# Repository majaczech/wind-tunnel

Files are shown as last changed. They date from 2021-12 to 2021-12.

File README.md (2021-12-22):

# 3D Printed Wind Tunnel
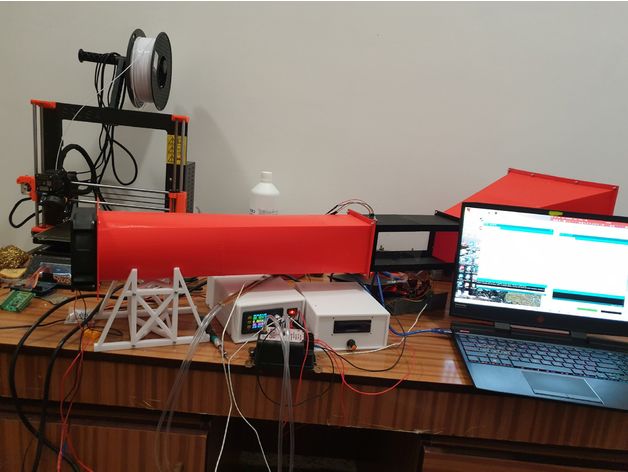
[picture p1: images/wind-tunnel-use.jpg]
3D Printed Wind Tunnel


This is 3D printed wind tunnel with Arduino-based unit. 

This source describes Open Hardware and is licensed under the CERN-OHL-S v2

**Experience with Arduino platform is required and supervision from a qualified electric engineering professional.**

**The project is prototype under development and authors are not responsible for any damages or injuries caused by inappropriate construction or operation.**
**This source is distributed WITHOUT ANY EXPRESS OR IMPLIED WARRANTY, INCLUDING OF MERCHANTABILITY, SATISFACTORY QUALITY AND FITNESS FOR A PARTICULAR PURPOSE.**

# References
1.	B.J. McCaffrey, G. Heskestad,A robust bidirectional low-velocity probe for flame and fire application, Combustion and Flame, Volume 26, 1976, Pages 125-127, ISSN 0010-2180, https://doi.org/10.1016/0010-2180(76)90062-6.
2.	Mauro, Stefano & Lanzafame, Rosario & Messina, Michele & Brusca, S. & Famoso, Fabio & Galvagno, Antonio. (2017). Small-Scale Open-Circuit Wind Tunnel: Design Criteria, Construction and Calibration. International Journal of Applied Engineering Research. 12. 13649-13662.
3.	The JeeLabs Shop. (n.d.). Retrieved February 11, 2021, from https://www.digitalsmarties.net/products/wind-sensor-rev-p
4.	Wind sensor REV. p - low Cost Anemometer. (n.d.). Retrieved February 12, 2021, from https://moderndevice.com/product/wind-sensor-rev-p/
5.	How can i tell if a case fan is sucking or blowing air? (2019, December 30). Retrieved February 13, 2021, from https://www.computerhope.com/issues/ch001151.htm
6.	Prohasky, Daniel & Watkins, Simon. (2014). Low cost hot-element anemometry versus the TFI Cobra.
7.	Thingiverse.com. (n.d.). The ultimate box maker BY HEARTMAN. Retrieved February 12, 2021, from https://www.thingiverse.com/thing:1264391
8.	T H Yong and S S Dol 2015 IOP Conf. Ser.: Mater. Sci. Eng. 78 012039

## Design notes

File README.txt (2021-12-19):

This thing was created by Majaczech, and is licensed under cc-sa.

Bench-Scale Wind-Tunnel for Callibration Pressure Probes accesible also from Thingiverse: https://www.thingiverse.com/thing:4601994

In order to safely built and operate the testing apparatus, experience with Arduino platform is required and supervision from a qualified electric engineering professional.

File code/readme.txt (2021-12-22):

This is improved demo sketch file from http://moderndevice.com/product/wind-sensor-rev-p/

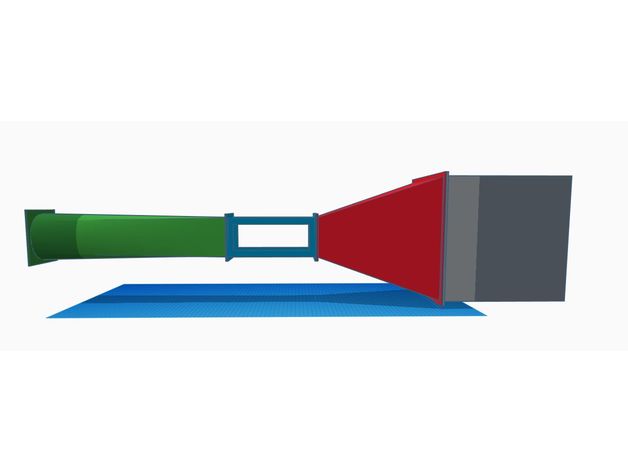
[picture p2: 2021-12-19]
images/Design.jpg

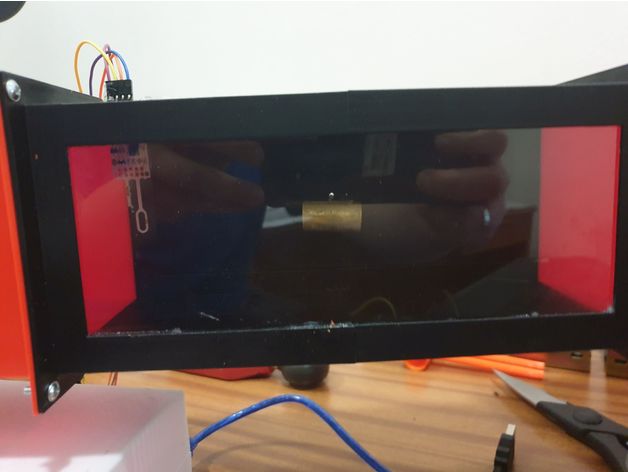
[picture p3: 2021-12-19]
images/BDVP-callibration.jpg

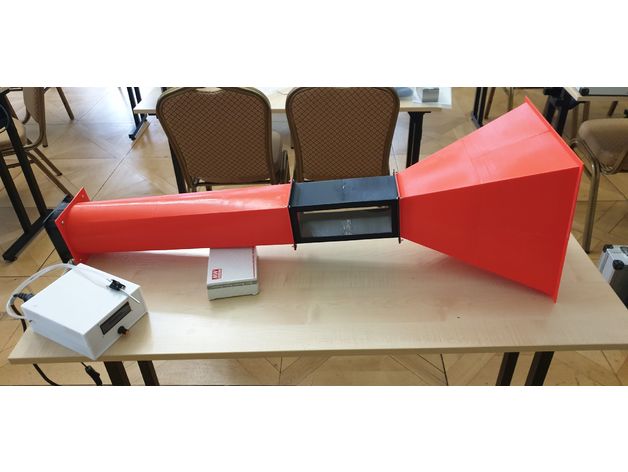
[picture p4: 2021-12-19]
images/Tunnel-2.jpg

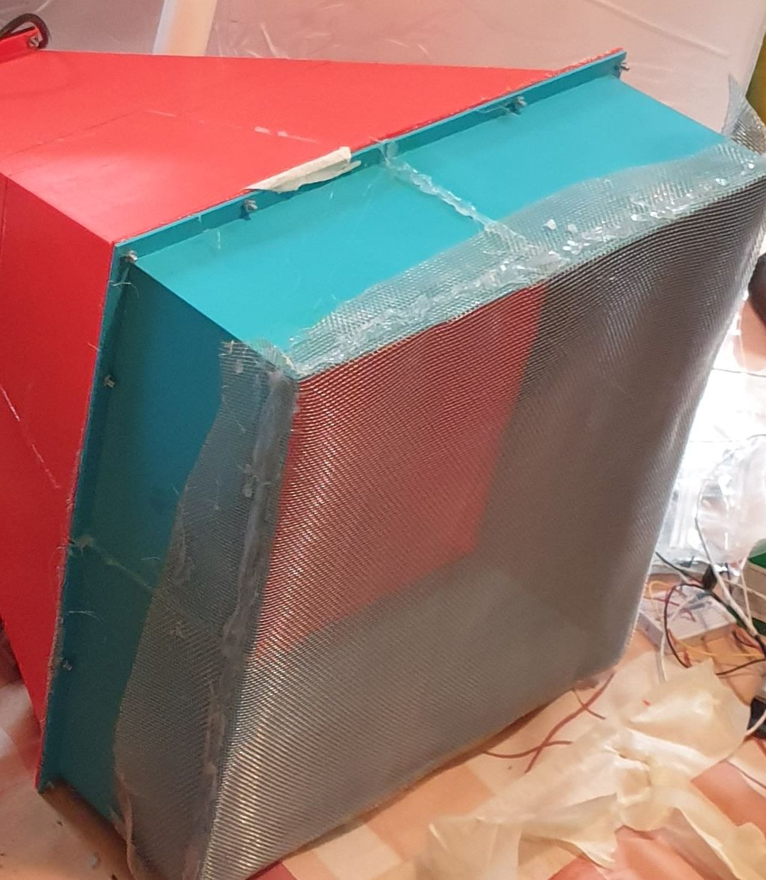
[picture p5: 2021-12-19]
images/settling-section.jpg

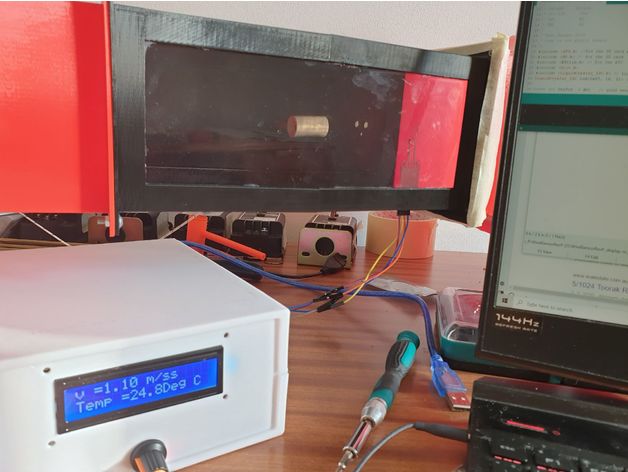
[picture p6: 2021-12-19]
images/in-sude.jpg

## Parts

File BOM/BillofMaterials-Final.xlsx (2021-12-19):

Designator | Component | Number | Cost per unit | Total cost [€] | Source of materials | Material type | WWW
 |  |  | [€]
Arduino UNO | Arduino Uno | 1 | 20 | 20 | Arduino | Electronics | https://store.arduino.cc/arduino-uno-rev3
LCD Display | Standard LCD 16x2 + extras - white on blue | 1 | 8.21 | 8.21 | Adafruit | Electronics | https://www.adafruit.com/product/181
i2c backpack | i2c / SPI character LCD backpack | 1 | 8.21 | 8.21 | Adafruit | Electronics | https://www.adafruit.com/product/292
12V DC power adapter | 12V DC 1000mA (1A) regulated switching power adapter - UL listed | 1 | 7.38 | 7.38 | Adafruit | Electronics | https://www.adafruit.com/product/798
Rev.P | Rev.P – Hot-wire anemometer | 1 | 24.75 | 24.75 | The JeeLabs Shop | Electronics | https://www.digitalsmarties.net/products/wind-sensor-rev-p
PWM regulator control | Fan Regulator - PWM regulator 6-28V 3A | 1 | 2.72 | 2.72 | Dratek | Electronics | https://dratek.cz/arduino/1141-pwm-regulator-otacek-motoru-dc-6v-28v-3a.html
Fan | Fan - Ventilator SUNON PMD2412PMB1-A(2).GN | 1 | 15.12 | 15.12 | GM electronic | Electronics | https://www.gme.cz/ventilator-sunon-pmd2412pmb1-a
24VDC power supply | Mean Well, 15W Embedded Switch Mode Power Supply SMPS, 24V dc, Enclosed | 1 | 13 | 13 | RS Components | Electronics | https://uk.rs-online.com/web/p/embedded-switch-mode-power-supplies-smps/0413605/
Filament | Fillament Prusament PET-G | 2 | 27.17 | 54.34 | Prusa | PET-G | https://shop.prusa3d.com/cs/prusament/802-prusament-petg-jet-black-1kg.html
M3 screws | Uxcell a15070200ux0058 M3 x 12mm 304 Stainless Steel Phillips Head Screws (Pack of 60) | 1 | 4.49 | 4.49 | Amazon | Steel | https://www.amazon.de/-/en/Uxcell-a15070200ux0058-Stainless-Phillips-Screws/dp/B012TE1TBS
M3 nuts | M3 Full Nut (50 Pack) 3mm A2 Stainless Steel Hex Hexagon Nuts | 1 | 3.79 | 3.79 | Amazon | Steel | https://www.amazon.de/-/en/Hex-Nuts-DIN-934-Stainless/dp/B07JX9BFCB?s=diy
Transparent shield | Rayher 3873600 Transparent Film PET, 30 x 40 cm, Thickness 0.4 mm, Windmill Film, Mobile Film, Sturdy, Transparent Film for Crafts | 1 | 6.69 | 6.69 | Amazon | PET-G | https://www.amazon.de/-/en/Rayher-3874800-Transparent-Film-Thick/dp/B004P141NM
Wires | YV Gear Wire Assortment, 0.50 mm, copper Tinned, 2x 25 m Reel Red/Black | 1 | 7.95 | 7.95 | Amazon | Wires | https://www.amazon.de/-/en/Assortment-0-50-copper-Tinned-Black/dp/B01CME8WPG?s=diy
IEC Socket | IEC Male Chassis Power Plug with Fuseholder | 1 | 2.1 | 2.1 | GM electronic | Electronics | https://www.gme.cz/napajeci-euro-konektor-gsi-2
Fuse | Fuse 5x20 - 1.6A | 1 | 0.17 | 0.17 | GM electronic | Electronics | https://www.gme.cz/pojistka-trubickova-f-1-6a-5x20
Power Switch - Fan | ON - OFF Power Switch MIRS-201A-C3-R/B 230V | 1 | 0.97 | 0.97 | GM electronic | Electronics | https://www.gme.cz/kolebkovy-spinac-mirs-201a-c3-r-b-230v
Power cable | PremiumCord Power Cable | 1 | 3.29 | 3.29 | Amazon | Electronics | https://www.amazon.de/-/en/kpsp3-PremiumCord-Power-Cable/dp/B00AOAJ78M
Solder wire | Solder Wire | 1 | 6.99 | 6.99 | Amazon | Solder | https://www.amazon.de/-/en/Solder-Wire-Lead-Free-Rosin-Core/dp/B07Z75HQD5?s=diy
Jumper | Premium Female/Female Jumper Wires - 20 x 6" (150mm) | 1 | 1.61 | 1.61 | Adafruit | Wires | https://www.adafruit.com/product/1950
Jumper | Premium Male/Male Jumper Wires - 20 x 6" (150mm | 1 | 1.61 | 1.61 | Adafruit | Wires | https://www.adafruit.com/product/1957
Jumper | Premium Female/Female Jumper Wires - 20 x 6" (150mm) | 1 | 1.61 | 1.61 | Adafruit | Wires | https://www.adafruit.com/product/1950
Mesh | Onpira Fly Net / Fly Screen 1 m / Aluminium | 1 | 8.95 | 8.95 | Amazon | Mesh | https://www.amazon.de/-/en/Onpira-Materials-Galvanised-Aluminium-Stainless/dp/B01N6O9205
Screws M2 | sourcing map Pack of 50 Self-Tapping Screws Phillips Head 304 Stainless Steel Connection Bolts 2 x 8 mm | 1 | 7.82 | 7.82 | Amazon | Steel | https://www.amazon.de/-/en/sourcing-Self-Tapping-Phillips-Stainless-Connection/dp/B07QKQYNFB
Silicone | Fischer premium construction silicone, 53090 | 1 | 4.82 | 4.82 | Amazon | Silicone | https://www.amazon.de/-/en/Fischer-premium-construction-silicone-53090/dp/B001JM0O5O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
 |  |  |  | 216.59

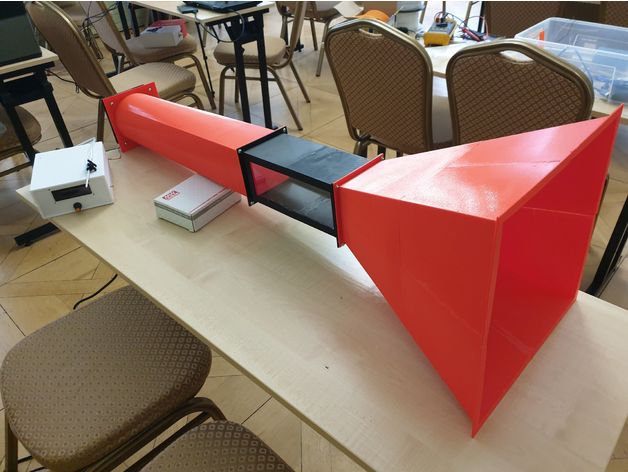
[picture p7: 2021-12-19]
images/printed-parts2.jpg

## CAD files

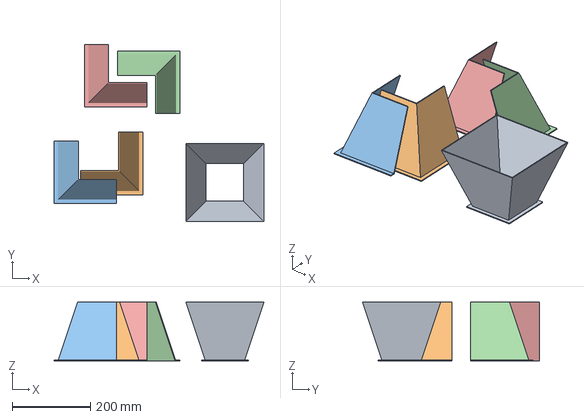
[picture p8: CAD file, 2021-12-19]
STL/Contraction.3mf
537.4 x 453.0 x 150.0 mm
Contraction.stl x 5

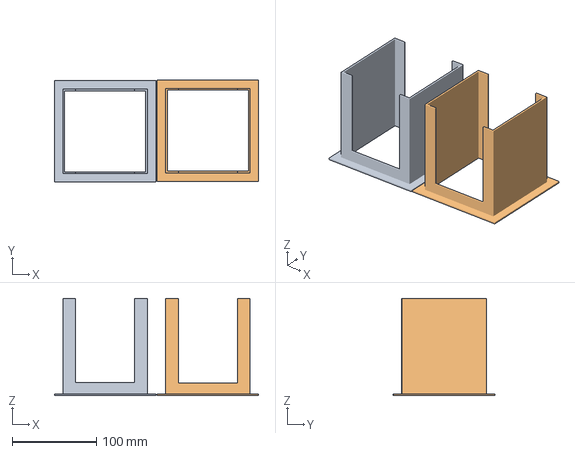
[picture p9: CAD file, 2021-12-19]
STL/Testing-Chamber.3mf
241.5 x 120.7 x 115.0 mm
Testing-Chamber.stl x 2

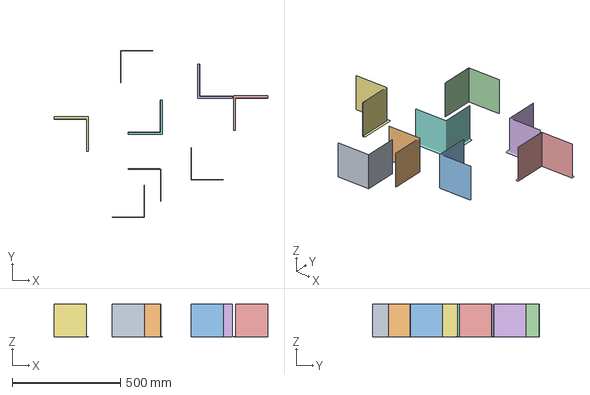
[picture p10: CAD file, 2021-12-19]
STL/Settling.3mf
987.4 x 771.1 x 151.0 mm
Settling.stl x 8

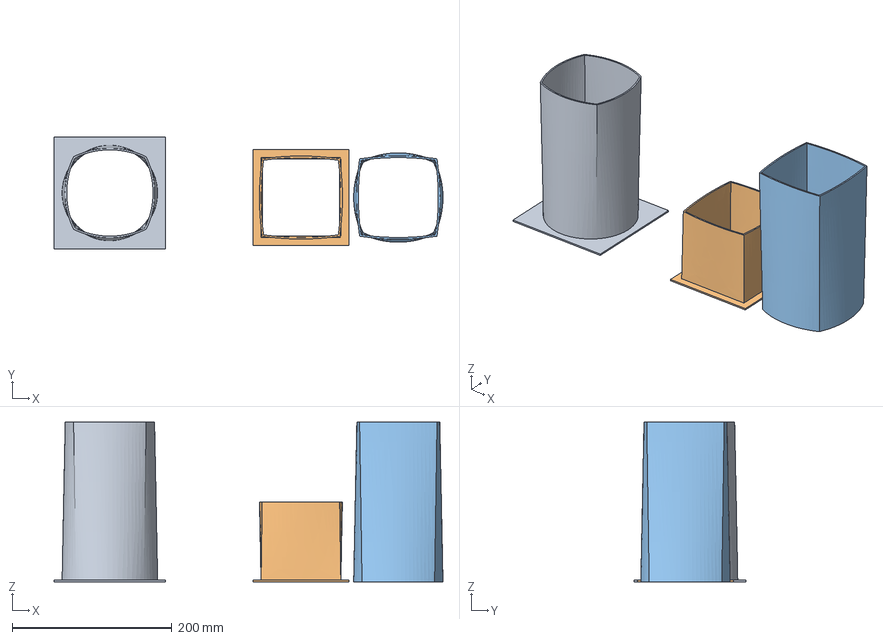
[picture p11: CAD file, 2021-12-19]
STL/Diffuser.3mf
487.3 x 140.0 x 200.0 mm
Diffuser.stl x 3

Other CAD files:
STL/Contraction.stl
STL/Diffuser.stl
STL/Settling.stl
STL/Testing-Chamber.stl

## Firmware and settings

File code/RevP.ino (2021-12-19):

/* This is improved demo sketch for the Modern Device Rev P Wind Sensor
* Requires a Wind Sensor Rev P from Modern Device
* http://moderndevice.com/product/wind-sensor-rev-p/
* 
* The Rev P requires at least at least an 8 volt supply. The easiest way to power it 
* if you are using an Arduino is to use a 9 volt or higher supply on the external power jack
* and power the sensor from Vin.
* 
* Hardware hookup 
* Sensor     Arduino Pin
* Ground     Ground
* +10-12V      Vin
* Out          A0
* TMP          A2
*
* Paul Badger 2014
* code in the public domain
*/

#include <SPI.h> //for the SD card module
#include <SD.h> // for the SD card
#include <RTClib.h> // for the RTC
#include <Wire.h>
#include <LiquidCrystal_I2C.h> // LiquidCrystal_I2C library
LiquidCrystal_I2C lcd(0x27, 16, 2); // 0x27 is the i2c address of the LCM1602 IIC v1 module (might differ)

const int OutPin  = A0;   // wind sensor analog pin  hooked up to Wind P sensor "OUT" pin
const int TempPin = A2;   // temp sesnsor analog pin hooked up to Wind P sensor "TMP" pin




void setup() {
    Serial.begin(9600);
    lcd.init();
    lcd.setBacklight(255);
    lcd.begin(16, 2);
    lcd.setCursor(0,0);
}

void loop() {

    // read wind
    int windADunits = analogRead(OutPin);
    // Serial.print("RW ");   // print raw A/D for debug
    // Serial.print(windADunits);
    // Serial.print("\t");
    
    
    // wind formula derived from a wind tunnel data, annemometer and some fancy Excel regressions
    // this scalin doesn't have any temperature correction in it yet
    float windMPH =  pow((((float)windADunits - 264.0) / 85.6814), 3.36814);
//    Serial.print(windMPH);
 //   Serial.print(" MPH\t");   
    Serial.print(windMPH*0.44704,2);
    Serial.print(" M/s\t");
  //  Serial.print(windMPH*1.609,2);
 //   Serial.print(" KmPH\t");
    lcd.setCursor(0,0);  
    lcd.print("v =");
    lcd.print(windMPH*0.44704,2);
    lcd.print(" m/s");
    
    // temp routine and print raw and temp C
    int tempRawAD = analogRead(TempPin);  
    // Serial.print("RT ");    // print raw A/D for debug
    // Serial.print(tempRawAD);
    // Serial.print("\t");
    
    // convert to volts then use formula from datatsheet 
    // Vout = ( TempC * .0195 ) + .400
    // tempC = (Vout - V0c) / TC   see the MCP9701 datasheet for V0c and TC
    
    float tempC = ((((float)tempRawAD * 5.0) / 1024.0) - 0.400) / .0195; 
    Serial.print(tempC,1);
    Serial.println(" C");
    lcd.setCursor(0,1);  
    lcd.print("Temp =");
    lcd.print(tempC,1);
    lcd.print("Deg C");
    delay(1000);
}
